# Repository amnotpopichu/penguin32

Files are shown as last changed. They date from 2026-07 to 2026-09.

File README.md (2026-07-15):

# penguin32
Penguin32 is a esp32 devboard developed on the esp32 s3fn8 board but with a big penguin on it. why penguin? why not? the main goal here was to develop and learn bare chip work

# Firmware + CAD
N/A, all the necessary programs are preflashed onto the s3 chip. Also no cad for obvious reasons, its just a devboard

# Images
Not sure why some of the models dont actaully render, and some are upside down, so forgive the pcb looking kinda odd.
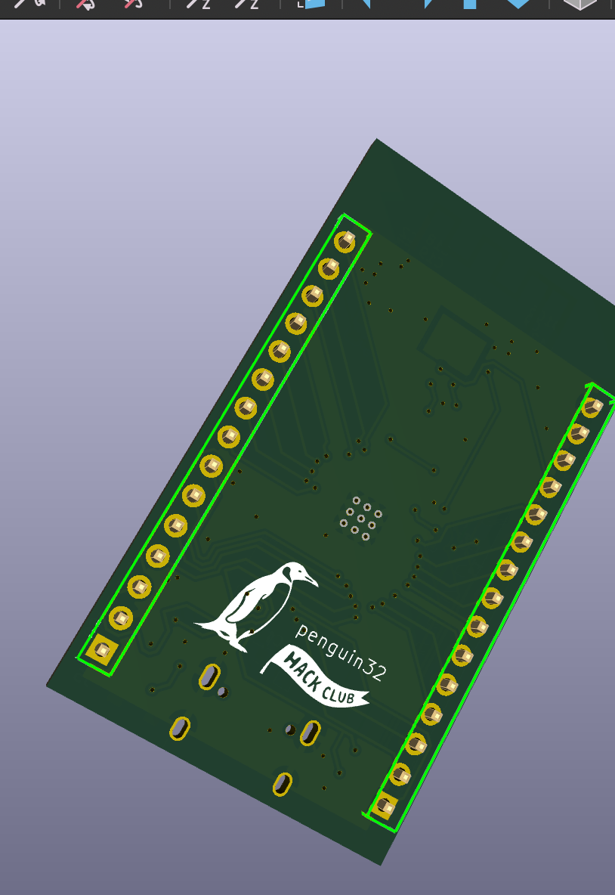
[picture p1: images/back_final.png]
image name

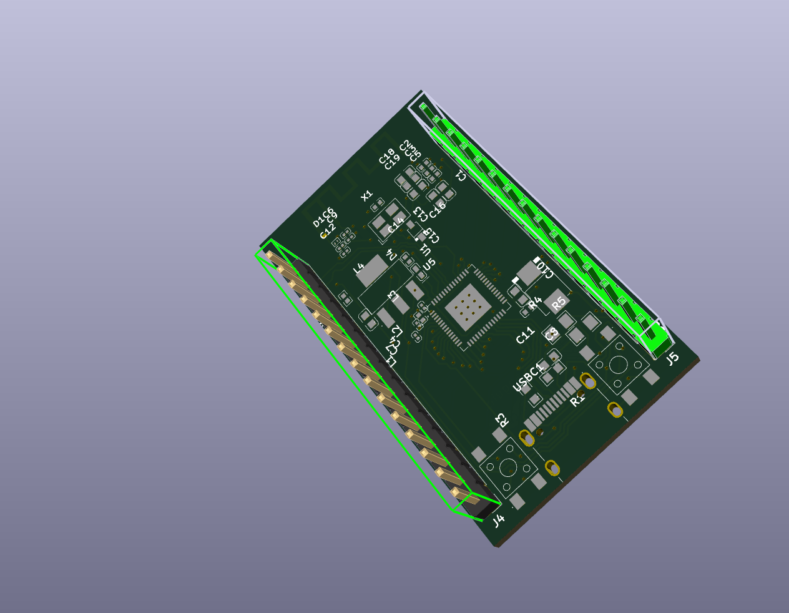
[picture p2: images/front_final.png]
image name

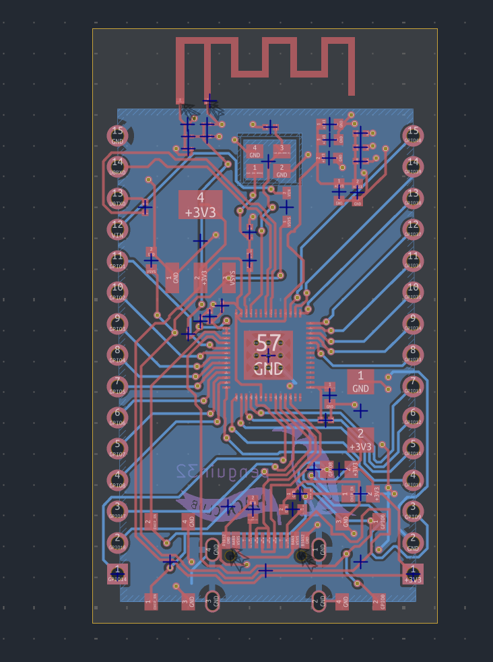
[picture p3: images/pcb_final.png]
image name

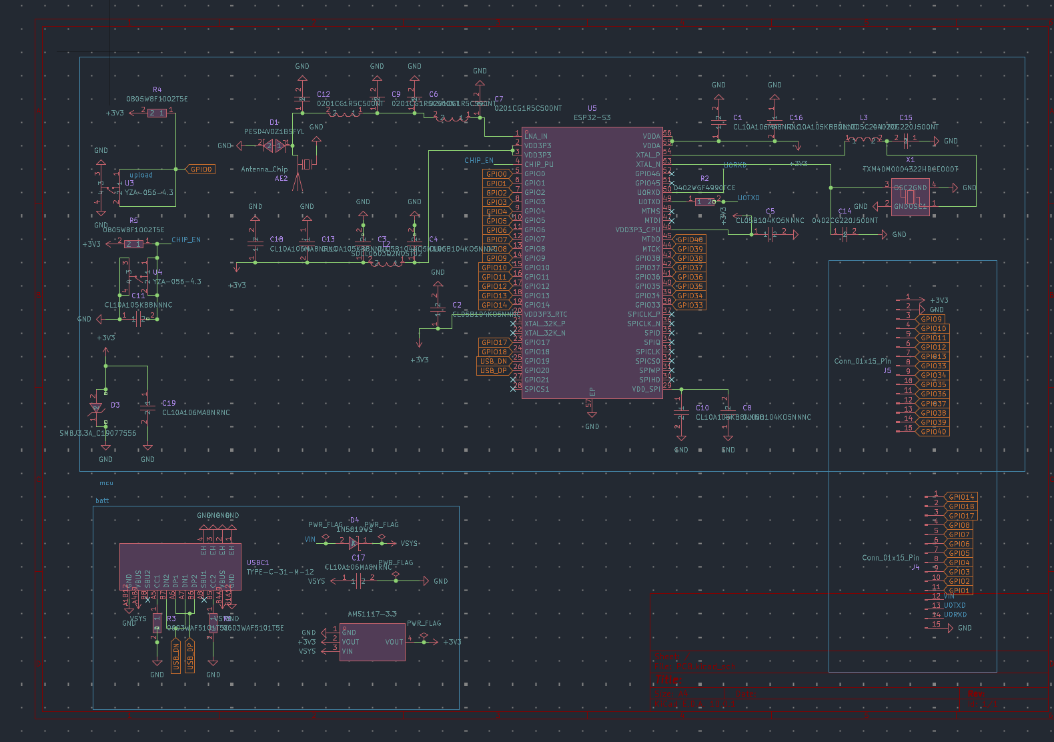
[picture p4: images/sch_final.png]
image name

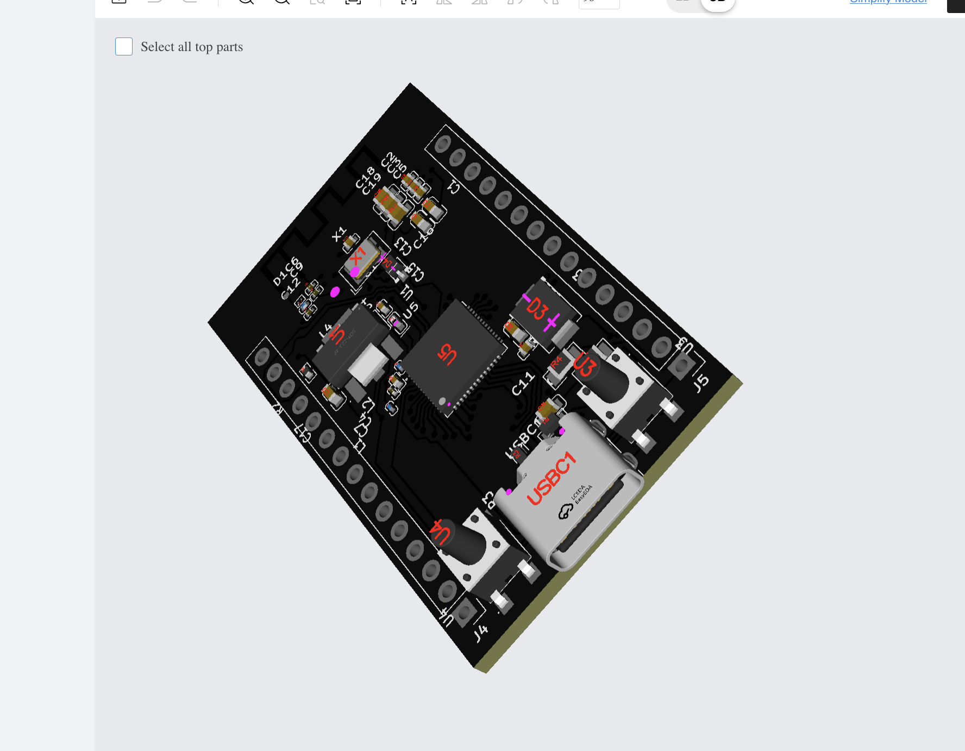
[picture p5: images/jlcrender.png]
image name


# Notes
flash not needed thanks to the onboard flash. this is my first time doing bare chip development so im pretty happy with how it turned out given i did it in about 3 days to attempt to qualify for outpost. Honestly i can't believe some of the stuff (routing) took me so long, but i guess i finished at the end of the day so its fine. Also i have two seperate BOMs, a regular BOM, and then a BOM for specific pick and place components. Also i had to use 5 pcba instead of 2, because otherwise it would have made do standard pcba -- which is more expenisve. gsdl doesnt work because jlc doesn't allow it over a certain price.

| Line Item | Amount (USD) |
|---|---|
| MERCHANDISE TOTAL | 65.78 |
| SHIPPING CHARGE | 42.78 |
| Customs duties & taxes | 17.78 |
| DISCOUNT | -15.00 |
| SALES TAX | 4.90 |
| ORDER TOTAL | 116.24 |

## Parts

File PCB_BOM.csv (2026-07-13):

Reference | Qty | Value | DNP | Exclude from BOM | Exclude from Board | Footprint | Datasheet
AE2 | 1 | Antenna_Chip |  |  |  | esp32 antenna:ESPRESSIF_ESP32_MIFA_2.4GHz_Right
C1,C17,C18,C19 | 4 | CL10A106MA8NRNC |  |  |  | easyeda2kicad:C0603 | https://lcsc.com/product-detail/Multilayer-Ceramic-Capacitors-MLCC-SMD-SMT_SAMSUNG_CL10A106MA8NRNC_10uF-106-20-25V_C96446.html
C2,C3,C4,C5,C8 | 5 | CL05B104KO5NNNC |  |  |  | easyeda2kicad:C0402 | https://lcsc.com/product-detail/Multilayer-Ceramic-Capacitors-MLCC-SMD-SMT_SAMSUNG_CL05B104KO5NNNC_100nF-104-10-16V_C1525.html
C6,C7,C9,C12 | 4 | 0201CG1R5C500NT |  |  |  | easyeda2kicad:C0201 | https://lcsc.com/product-detail/Multilayer-Ceramic-Capacitors-MLCC-SMD-SMT_1-5pF-1R5-0-25pF-50V_C50389.html
C10,C11,C13,C16 | 4 | CL10A105KB8NNNC |  |  |  | easyeda2kicad:C0603 | https://lcsc.com/product-detail/Multilayer-Ceramic-Capacitors-MLCC-SMD-SMT_SAMSUNG_CL10A105KB8NNNC_1uF-105-10-50V_C15849.html
C14,C15 | 2 | 0402CG220J500NT |  |  |  | easyeda2kicad:C0402 | https://lcsc.com/product-detail/Multilayer-Ceramic-Capacitors-MLCC-SMD-SMT_22pF-220-5-50V_C1555.html
D1 | 1 | PESD4V0Z1BSFYL |  |  |  | easyeda2kicad:DSN0603-2_L0.7-W0.3-P0.40-BI | https://lcsc.com/product-detail/presales_Nexperia-PESD4V0Z1BSFYL_C552547.html
D3 | 1 | SMBJ3.3A_C19077556 |  |  |  | easyeda2kicad:SMB_L4.6-W3.6-LS5.3-RD | https://www.lcsc.com/datasheet/C19077556.pdf
D4 | 1 | 1N5819WS |  |  |  | easyeda2kicad:SOD-323_L1.8-W1.3-LS2.5-RD | https://lcsc.com/product-detail/Others_B5819WS_C191023.html
J4,J5 | 2 | Conn_01x15_Pin |  |  |  | Connector_PinHeader_2.54mm:PinHeader_1x15_P2.54mm_Vertical
L1,L2,L4 | 3 | SDCL0603Q2N0ST02 |  |  |  | easyeda2kicad:L0201 | https://lcsc.com/product-detail/HF-Inductors_2nH-0-3nH_C42142.html
L3 | 1 | SDCL1005C24NJTDF |  |  |  | easyeda2kicad:L0402-RD | https://lcsc.com/product-detail/Inductors-SMD_24nH-5_C74301.html
R1,R3 | 2 | 0603WAF5101T5E |  |  |  | easyeda2kicad:R0603 | https://lcsc.com/product-detail/Chip-Resistor-Surface-Mount-UniOhm_5-1KR-5101-1_C23186.html
R2 | 1 | 0402WGF4990TCE |  |  |  | easyeda2kicad:R0402 | https://lcsc.com/product-detail/Chip-Resistor-Surface-Mount-UniOhm_499R-4990-1_C4125.html
R4,R5 | 2 | 0805W8F1002T5E |  |  |  | easyeda2kicad:R0805 | https://lcsc.com/product-detail/Chip-Resistor-Surface-Mount-UniOhm_10KR-1002-1_C17414.html
U1 | 1 | AMS1117-3.3 |  |  |  | easyeda2kicad:SOT-223-3_L6.5-W3.4-P2.30-LS7.0-BR | https://lcsc.com/product-detail/Low-Dropout-Regulators-LDO_AMS_AMS1117-3-3_AMS1117-3-3_C6186.html
U3,U4 | 2 | YZA-056-4.3 |  |  |  | easyeda2kicad:SW-SMD_4P-L4.5-W4.5-P3.00-LS6.8 | https://www.lcsc.com/datasheet/C49108646.pdf
U5 | 1 | ESP32-S3 |  |  |  | easyeda2kicad:QFN-56_L7.0-W7.0-P0.40-TL-EP4.0 | https://www.lcsc.com/datasheet/C2913196.pdf
USBC1 | 1 | TYPE-C-31-M-12 |  |  |  | easyeda2kicad:USB-C_SMD-TYPE-C-31-M-12_1 | https://lcsc.com/product-detail/USB-Type-C_Korean-Hroparts-Elec-TYPE-C-31-M-12_C165948.html
X1 | 1 | TXM40M0004322HBCEO00T |  |  |  | easyeda2kicad:CRYSTAL-SMD_4P-L3.2-W2.5-BL-2 | https://lcsc.com/product-detail/_Zhejiang-Abel-Elec-TXM40M0004322HBCEO00T_C284179.html

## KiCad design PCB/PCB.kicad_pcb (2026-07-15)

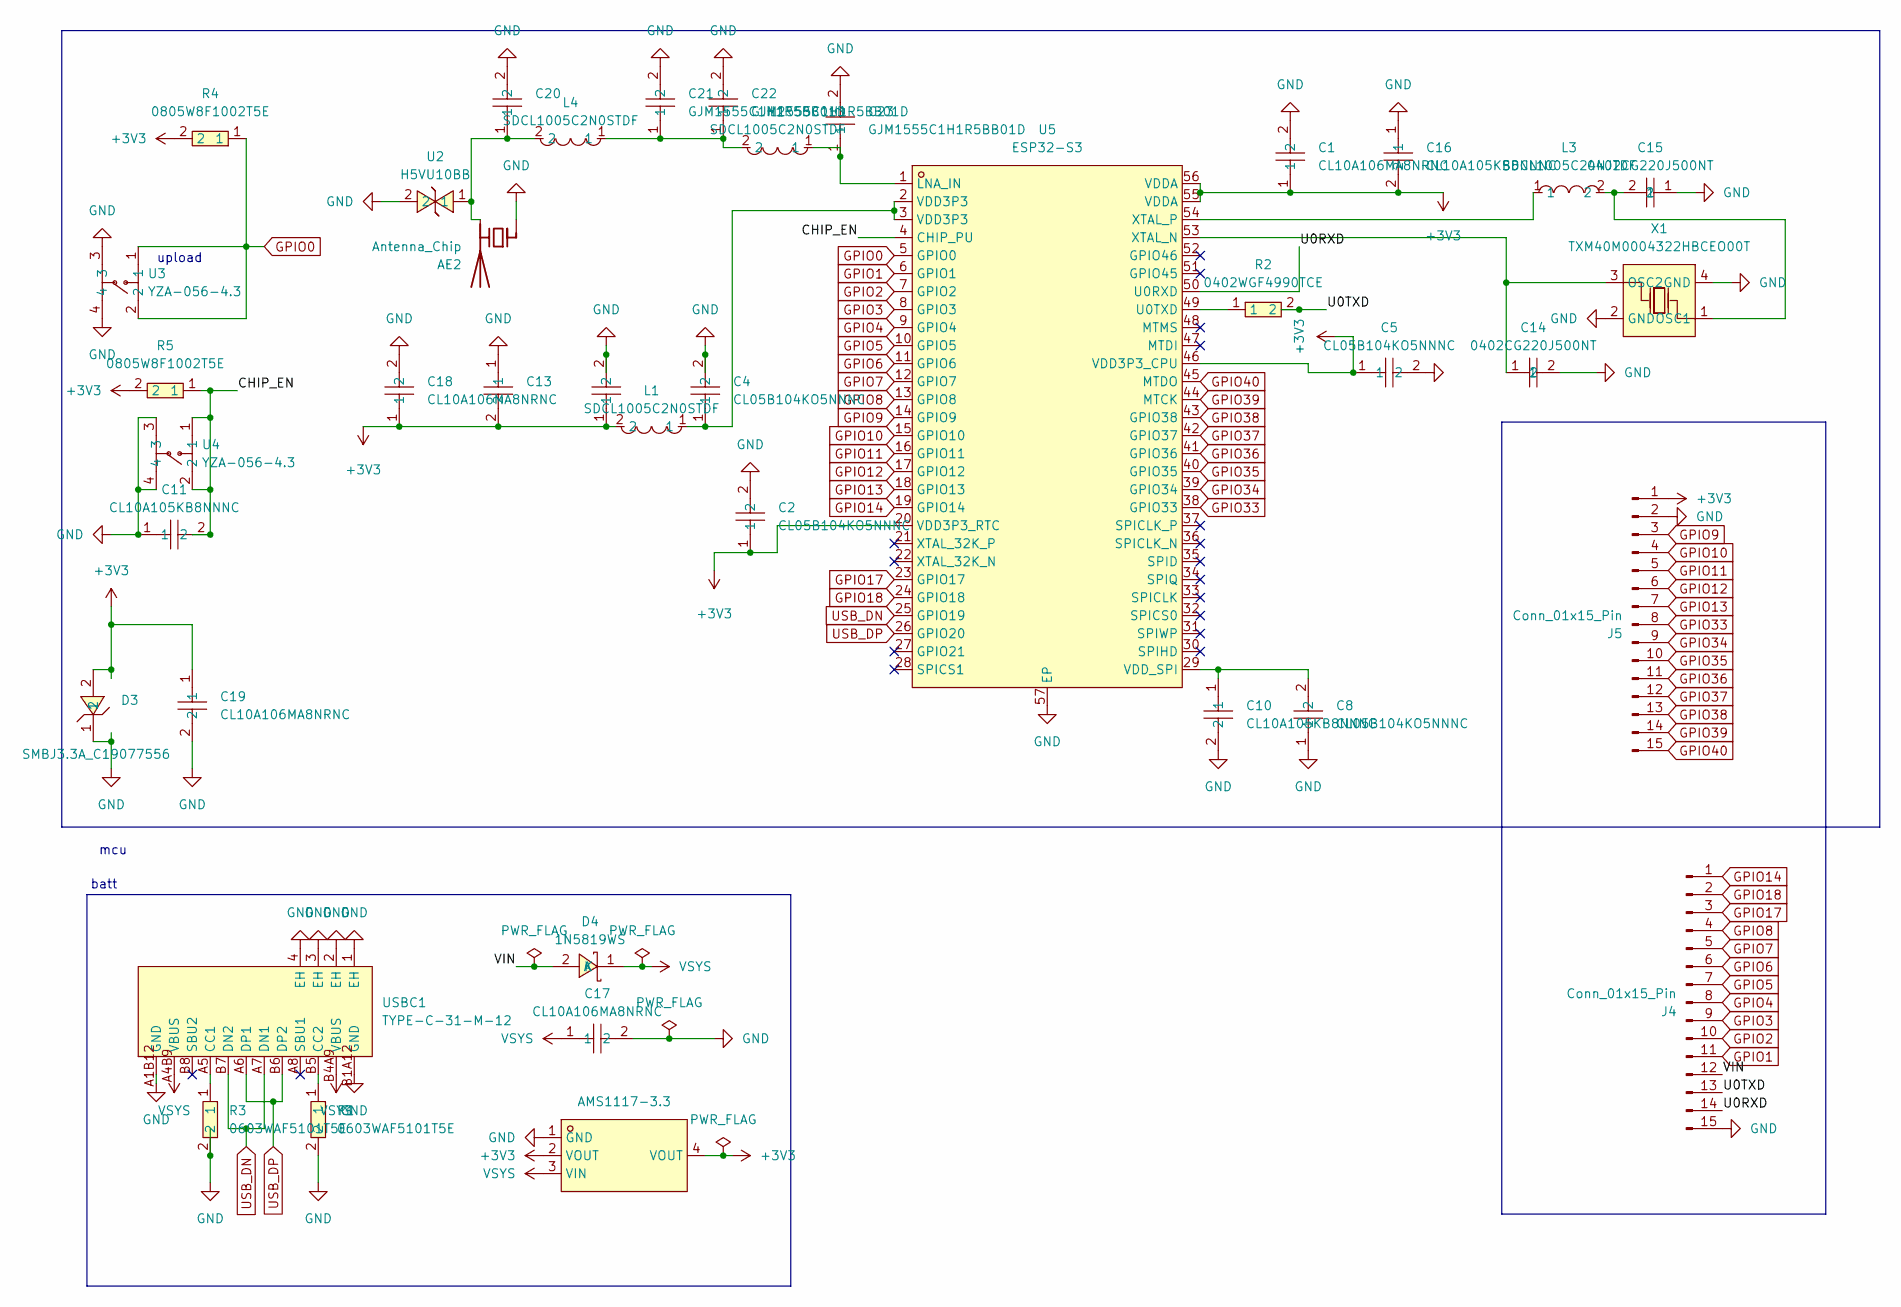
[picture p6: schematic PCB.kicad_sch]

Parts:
AE2: Antenna_Chip; ESPRESSIF_ESP32_MIFA_2.4GHz_Right
C1, C17, C18, C19: CL10A106MA8NRNC; C0603; MPN CL10A106MA8NRNC; LCSC Part C96446
C2, C3, C4, C5, C8: CL05B104KO5NNNC; C0402; MPN CL05B104KO5NNNC; LCSC Part C1525
C10, C11, C13, C16: CL10A105KB8NNNC; C0603; MPN CL10A105KB8NNNC; LCSC Part C15849
C14, C15: 0402CG220J500NT; C0402; MPN 0402CG220J500NT; LCSC Part C1555
C20, C21, C22, C23: GJM1555C1H1R5BB01D; C0402; MPN GJM1555C1H1R5BB01D; LCSC Part C76900
D3: SMBJ3.3A_C19077556; SMB_L4.6-W3.6-LS5.3-RD; MPN SMBJ3.3A; LCSC Part C19077556
D4: 1N5819WS; SOD-323_L1.8-W1.3-LS2.5-RD; MPN 1N5819WS; LCSC Part C191023
J4, J5: Conn_01x15_Pin; PinHeader_1x15_P2.54mm_Vertical
L1, L2, L4: SDCL1005C2N0STDF; L0402; MPN SDCL1005C2N0STDF; LCSC Part C43365
L3: SDCL1005C24NJTDF; L0402-RD; MPN SDCL1005C24NJTDF; LCSC Part C74301
R1, R3: 0603WAF5101T5E; R0603; MPN 0603WAF5101T5E; LCSC Part C23186
R2: 0402WGF4990TCE; R0402; MPN 0402WGF4990TCE; LCSC Part C4125
R4, R5: 0805W8F1002T5E; R0805; MPN 0805W8F1002T5E; LCSC Part C17414
U1: AMS1117-3.3; SOT-223-3_L6.5-W3.4-P2.30-LS7.0-BR; MPN AMS1117-3.3; LCSC Part C6186
U2: H5VU10BB; DFN1006-2L-BI; MPN H5VU10BB; LCSC Part C20615786
U3, U4: YZA-056-4.3; SW-SMD_4P-L4.5-W4.5-P3.00-LS6.8; MPN YZA-056-4.3; LCSC Part C49108646
U5: ESP32-S3; QFN-56_L7.0-W7.0-P0.40-TL-EP4.0; MPN ESP32-S3FN8; LCSC Part C2913196
USBC1: TYPE-C-31-M-12; USB-C_SMD-TYPE-C-31-M-12_1; MPN TYPE-C-31-M-12; LCSC Part C165948
X1: TXM40M0004322HBCEO00T; CRYSTAL-SMD_4P-L3.2-W2.5-BL-2; MPN TXM40M0004322HBCEO00T; LCSC Part C284179

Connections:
+3V3: C1.1, C2.1, C3.1, C5.1, C13.2, C16.2, C18.1, C19.1, D3.2, J5.1, L1.2, R4.2, R5.2, U1.2 (VOUT), U1.4 (VOUT), U5.20 (VDD3P3_RTC), U5.46 (VDD3P3_CPU), U5.55 (VDDA), U5.56 (VDDA)
/CHIP_EN: C11.2, R5.1, U4.1, U4.2, U5.4 (CHIP_PU)
/U0RXD: J4.14, U5.50 (U0RXD)
/U0TXD: J4.13, R2.2
/VIN: D4.2 (A), J4.12
GND: AE2.1 (FEED), C1.2, C2.2, C3.2, C4.2, C5.2, C8.1, C10.2, C11.1, C13.1, C14.2, C15.1, C16.1, C17.2, C18.2, C19.2, C20.2, C21.2, C22.2, C23.2, D3.1, J4.15, J5.2, R1.2, R3.2, U1.1 (GND), U2.2, U3.3, U3.4, U4.3, U4.4, U5.57 (EP), USBC1.1 (EH), USBC1.2 (EH), USBC1.3 (EH), USBC1.4 (EH), USBC1.A1B12 (GND), USBC1.B1A12 (GND), X1.2 (GND), X1.4 (GND)
GPIO0: R4.1, U3.1, U3.2, U5.5 (GPIO0)
GPIO1: J4.11, U5.6 (GPIO1)
GPIO2: J4.10, U5.7 (GPIO2)
GPIO3: J4.9, U5.8 (GPIO3)
GPIO4: J4.8, U5.9 (GPIO4)
GPIO5: J4.7, U5.10 (GPIO5)
GPIO6: J4.6, U5.11 (GPIO6)
GPIO7: J4.5, U5.12 (GPIO7)
GPIO8: J4.4, U5.13 (GPIO8)
GPIO9: J5.3, U5.14 (GPIO9)
GPIO10: J5.4, U5.15 (GPIO10)
GPIO11: J5.5, U5.16 (GPIO11)
GPIO12: J5.6, U5.17 (GPIO12)
GPIO13: J5.7, U5.18 (GPIO13)
GPIO14: J4.1, U5.19 (GPIO14)
GPIO17: J4.3, U5.23 (GPIO17)
GPIO18: J4.2, U5.24 (GPIO18)
GPIO33: J5.8, U5.38 (GPIO33)
GPIO34: J5.9, U5.39 (GPIO34)
GPIO35: J5.10, U5.40 (GPIO35)
GPIO36: J5.11, U5.41 (GPIO36)
GPIO37: J5.12, U5.42 (GPIO37)
GPIO38: J5.13, U5.43 (GPIO38)
GPIO39: J5.14, U5.44 (MTCK)
GPIO40: J5.15, U5.45 (MTDO)
unnamed: AE2.2 (PCB_Trace), C20.1, L4.2, U2.1
unnamed: C4.1, L1.1, U5.2 (VDD3P3), U5.3 (VDD3P3)
unnamed: C21.1, C22.1, L2.2, L4.1
unnamed: C23.1, L2.1, U5.1 (LNA_IN)
unnamed: R2.1, U5.49 (U0TXD)
unnamed: C8.2, C10.1, U5.29 (VDD_SPI)
unnamed: C14.1, U5.53 (XTAL_N), X1.3 (OSC2)
unnamed: L3.1, U5.54 (XTAL_P)
unnamed: R3.1, USBC1.A5 (CC1)
unnamed: R1.1, USBC1.B5 (CC2)
unnamed: C15.2, L3.2, X1.1 (OSC1)
USB_DN: U5.25 (GPIO19), USBC1.A7 (DN1), USBC1.B7 (DN2)
USB_DP: U5.26 (GPIO20), USBC1.A6 (DP1), USBC1.B6 (DP2)
VSYS: C17.1, D4.1 (K), U1.3 (VIN), USBC1.A4B9 (VBUS), USBC1.B4A9 (VBUS)

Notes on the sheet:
batt
upload
mcu

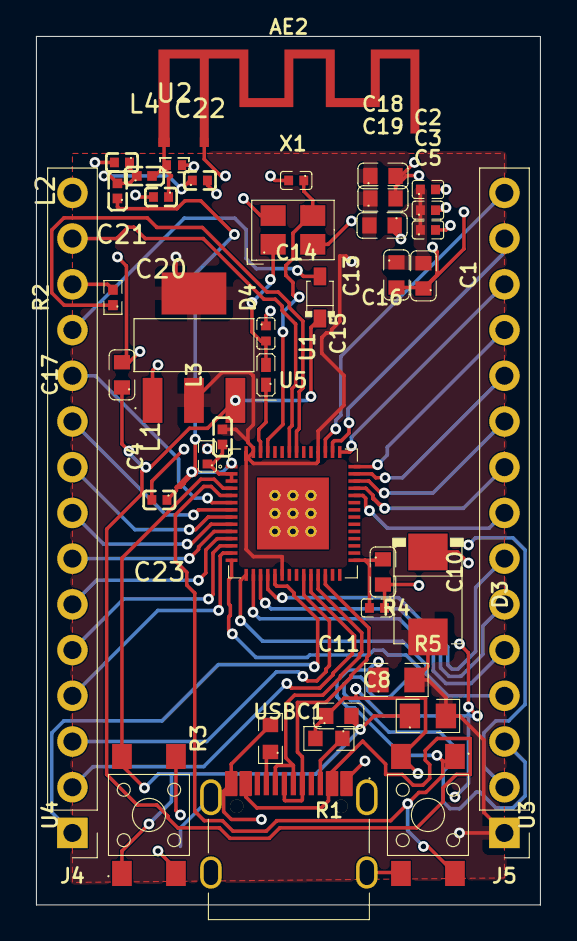
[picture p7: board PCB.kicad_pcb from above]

Board: 2 copper layers, 28.0 x 48.2 mm, 40 parts (0 on the bottom side), 45 nets.

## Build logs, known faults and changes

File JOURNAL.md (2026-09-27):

---
title: "Penguin32"
author: "Leo Hsia"
description: "Penguin32 is a esp32 devboard but with a big penguin on it. why penguin? why not?"
---
# September 8th
long story short they arrived -- i didnt journal, but there were issues with it heating up without powering on. eventually i grabbed a mulitimeter and tested it, finding the LDO only returned 0.5v. After asking around Ace6rings helped out a lot, and noticed I had forgotten some decop capacitators next to the LDO. very sad that i wasted so much, but the lesson is to never forget to read ldo datasheets (i ignorantly assumed ldos didnt need decoup caps). this project is kinda chopped now but next devboard WILL not have these mistakes

# Jul 14th: I DID IT
after emaliing jlcpcb i finally got a 15 dollar coupon to stay under my limit!! LETS GOOOO. order is now placed
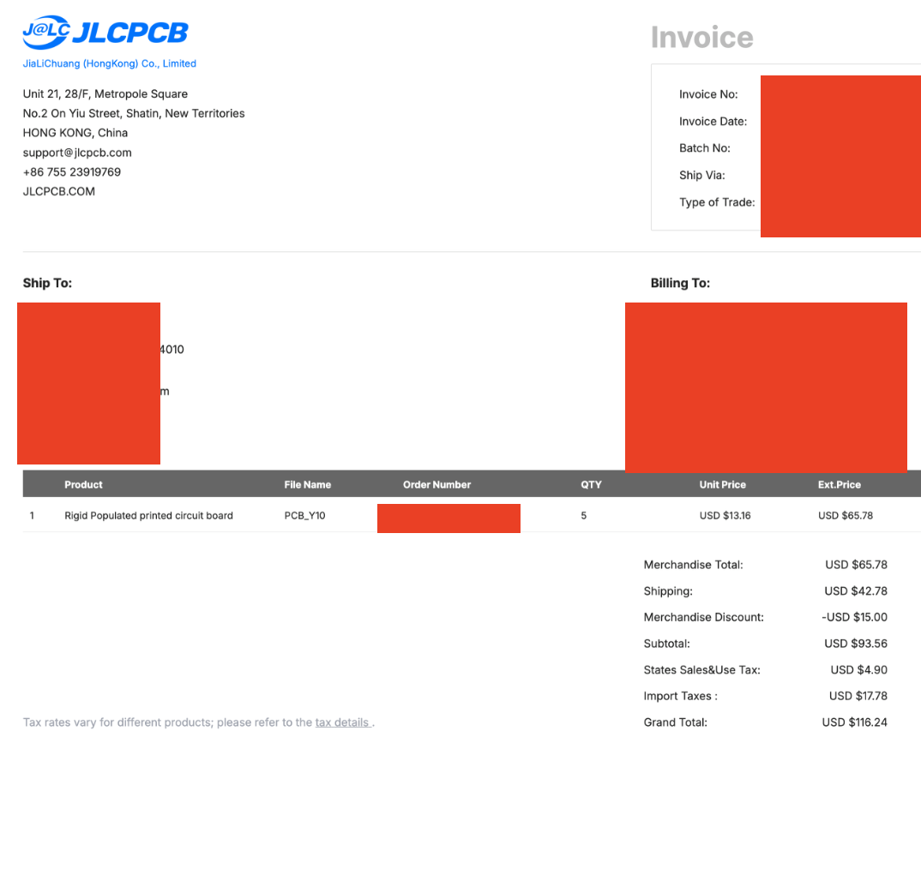
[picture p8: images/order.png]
image name

**Total time spent: 0.5 hours**

# Jul 13th: PCBA BOM
soo erm jlc decided they were going to slap on 60 dollars in hidden fees if i dont redo some parts (because im stupid and did small foot prints and that needs standard pcba instead of economic). went back and sourced a diff diode because of stock. also tried their customer support to get the review, reviewed on a second platform after being blocked on trust pilot (im trying again). tldr i just need 12 extra dollars. (or a 12 dollar discount) because gdsl is mean

**Total time spent: 0.5 hours**

# Jul 12th: rewire
I rerouted everything three times. i wish i was joking. anywyas some of the more techical and fun stuff. 1. rerouted because i changed some stuff where i was deciding how my headers should work (to optimize for placement) 2. changed because i optimized BOM. i had something that needed 2k capacitaors minmium order so i changed it to something else, and then in the process rerouted. 3. i just wasnt getting it done. i think with my past few attempts it just wasnt working, so i rerouted everything. All in all, i think there are a few things i learned 1. i should use a second plane next time, ie a 3v3 pwr plane instead of manually routing everything 2. sometimes i need to mess with footprints. i had to change some of the thermal pins to actaully route to ground for it to work, and then also had to learn about net ties (to stop kicad from yelling at me). didnt solve it, so i also learned about 4. ignoring drc when you are 100% sure you are right, and adding a comment. Also added some silkscreen stuff With a penguin and a cool hatck club flag.

image name
image name
image name
**Total time spent: 2.5 hours**
# Jul 11th: pcb wiring
i wish i was joking im writing this journal while im not even done with my wiring (half way through this session). the diff pair wiring has taken me AN HOUR. im so serious. i cannot for some reason get the width to match up and it took me >1 hour to actaully get it to work. genuienly i keep trying to fix this width and then having to fix the length and then over and over and over again. after wayy to long i have fully gotten what i believe to be as best possible solution, with the length delta to be <0.5mmish. time to move onto actaully doing ground pours! in total i logged 140 minutes but im going to self deflate to 105 because there were times i wasn't as productive enough + spending a full hour on diff pairs is ridiculous (even tho it took me that long). anyways the second hour was spent working on routing the thing and moving stuff around becasue i HATE this so much i should have managed this 10x better before starting tbh. im considering restarting routing at some point if this doesn't work out because honestly it doesn't look too good right now and im worried it wont work.can
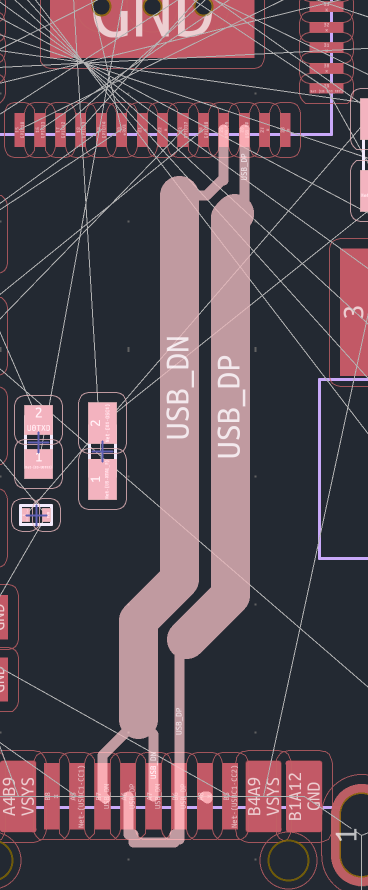
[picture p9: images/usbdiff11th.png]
image name

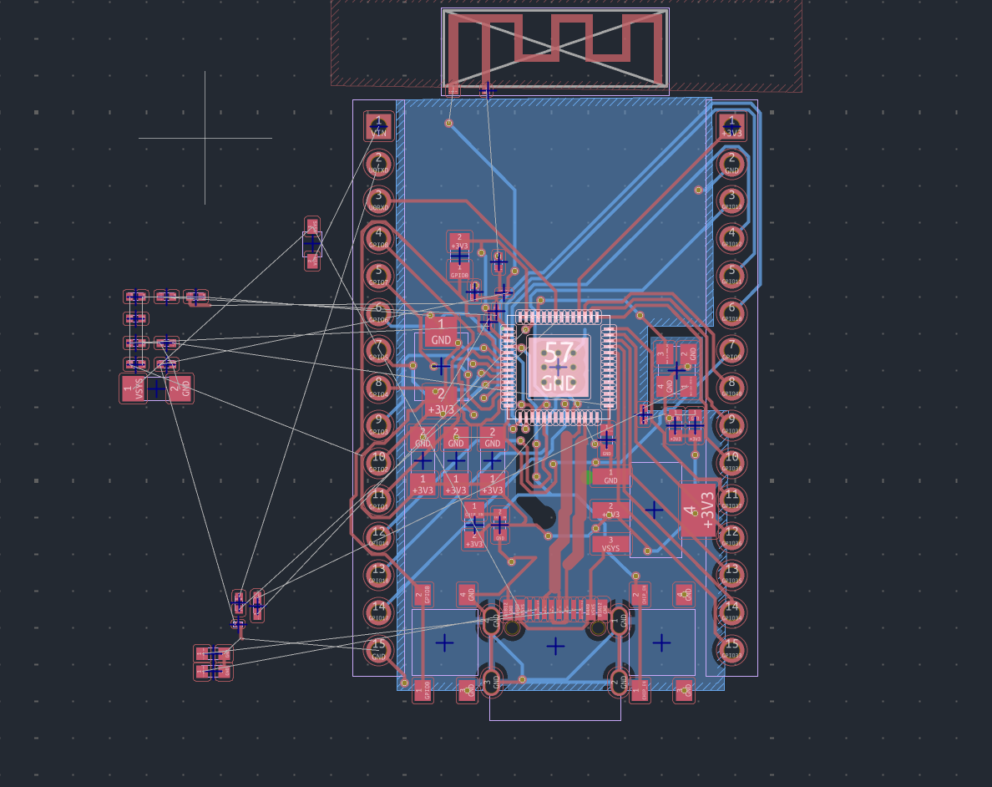
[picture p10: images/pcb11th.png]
image name

**Total time spent: 1.75 hours**

# Jul 11th: schematic done
assigned a lot of footprints cross checking parts with LCSC. took me stupidly long espeically because i have been struggling a lot with deal of the capicators because there is osmehow ZERO data about capacitators for certian parts of the wiring of the antenna. Luckily i managed to find a reasonabile range and have finished ALL the footprints which took a really long time. 
I also ended up catching myself with one of my diodes, and then added a final decopuler. (erc is lying to me and half of them is like pwr flag issues which arent even real). big thanks to [@jblitzar](https://github.com/jblitzar) for advice info on capacitator information for antenna.
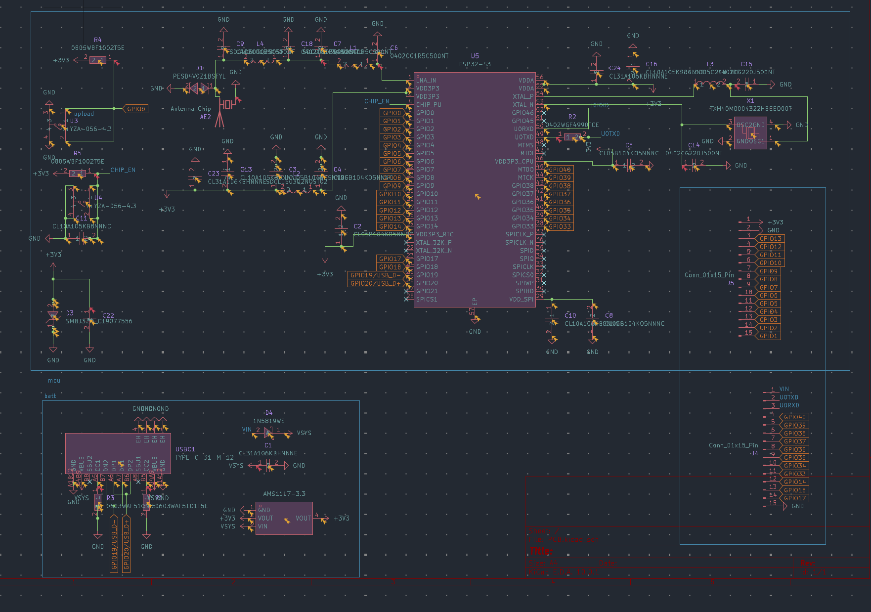
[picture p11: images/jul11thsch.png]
image name

**Total time spent: 1.5 hours**
# Jul 11th: short jouranl but came back rq
ok so guess who changed the ENTIRE esp32 schematic cus i needed to change the footprint for BOM later (im trying to limit as much of that pick and place instruction stuff). its pretty simpel i just rewired and moved things so image sort of speaks for itself. was not fun 0/10 would not recommend.
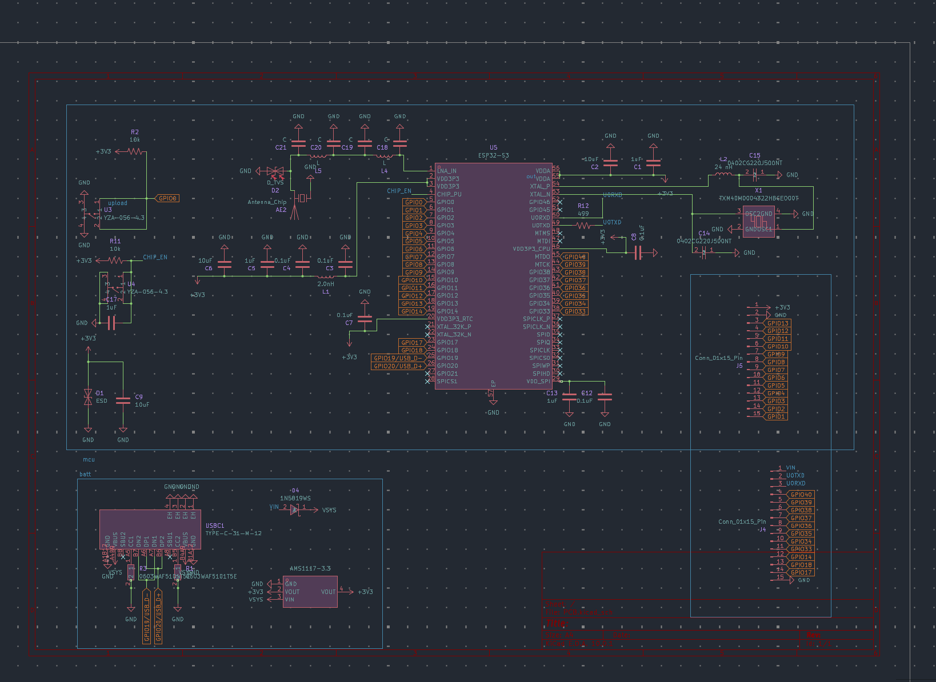
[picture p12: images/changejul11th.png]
image name

**Total time spent: 0.25 hours**
# Jul 10+11th: worked so much turned a new day 
footprint lowk got hands. okay but in all seriousness a few things happened.
1. crashed out at kicad because it was glitching out
2. crashed out at easyeda because it wasnt so easy (i thought i had to use easyeda to use easyeda2kicad until i read the docs)
3. crashed out at kicad again (this time for finding the symobls library instead of the package manager)
4. am actively crying over sourcing parts this is so sad
okay but really from some good advice from [@hekinav](https://github.com/hekinav) i simplified a lot of my battery stuff and used an LDO instead of a buck converter (because i dont have anything to boost!!!)i also started assigning a lot of footprints which is super fun (i hate it so much) but its so satisifying to keep on going through and checking things off. self (over)deflating myself a little because i got a bit distracted yapping so going from 2 hours to listed below
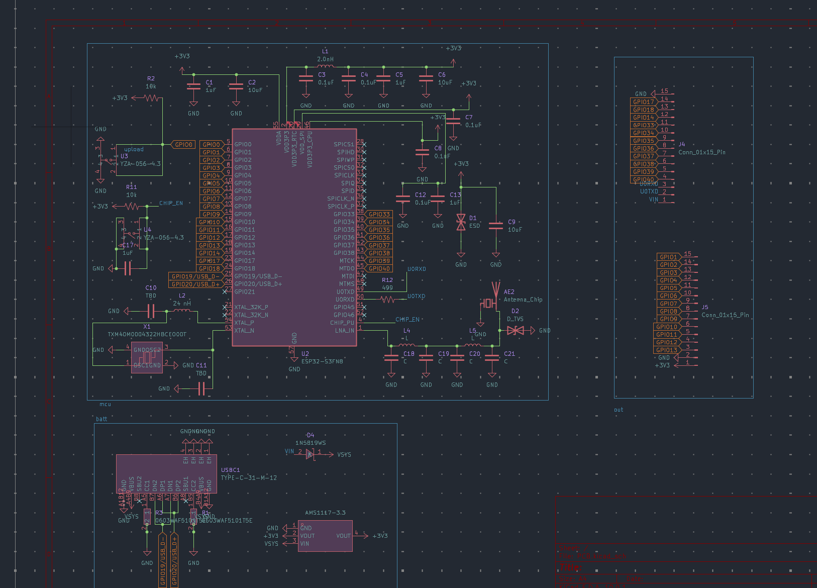
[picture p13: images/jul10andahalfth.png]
image name

**Total time spent: 1.25 hours**
# Jul 10th: sch work
yippie today has been focused on wiring stuff and getting it ready for devboard.
work includes: pin headers yay they exist now, a vin port! yippie hopefully this diode works, and i yoinked my esp32 from upstairs to figure out what to do. i also learned how antennas kinda work, and turns out its not really a thing you stick on as much as it is just traces which is kinda cool! so i imported from github. anywyas rest of time is just reviewing schematic + ect.
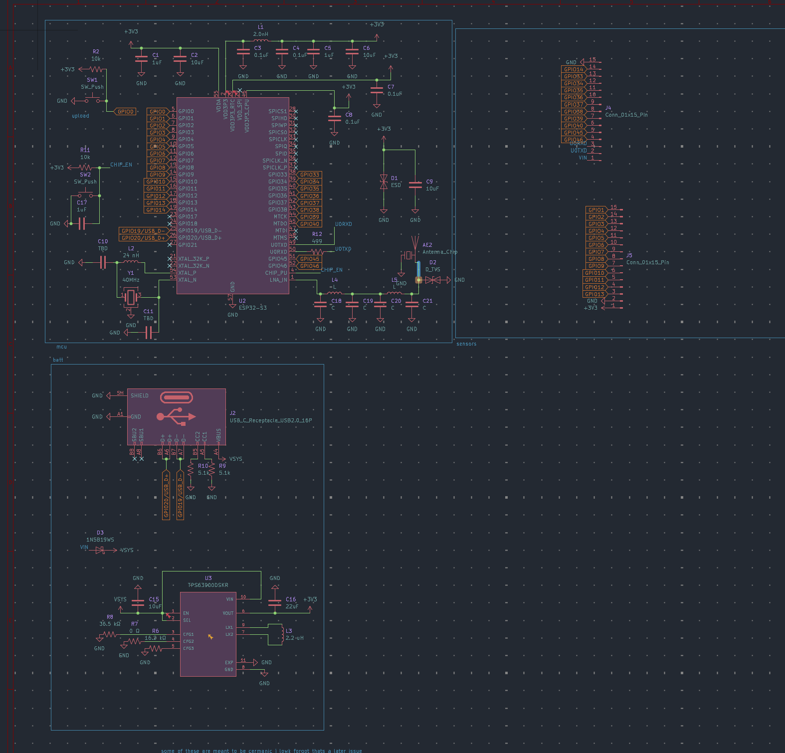
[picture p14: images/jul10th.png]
image name

**Total time spent: 0.75 hours**
# July 9th: Starting
Today i mainly just imported a bunch of stuff from a previous esp project, that was incomplete. This is super helpful, because i dont have to spend as much time doing the bare chip schematic work, but will have to do a lot of pcb work, and finish it up because I never included wifi + some other things. Most work included the LNA_in + rewiring some power lines
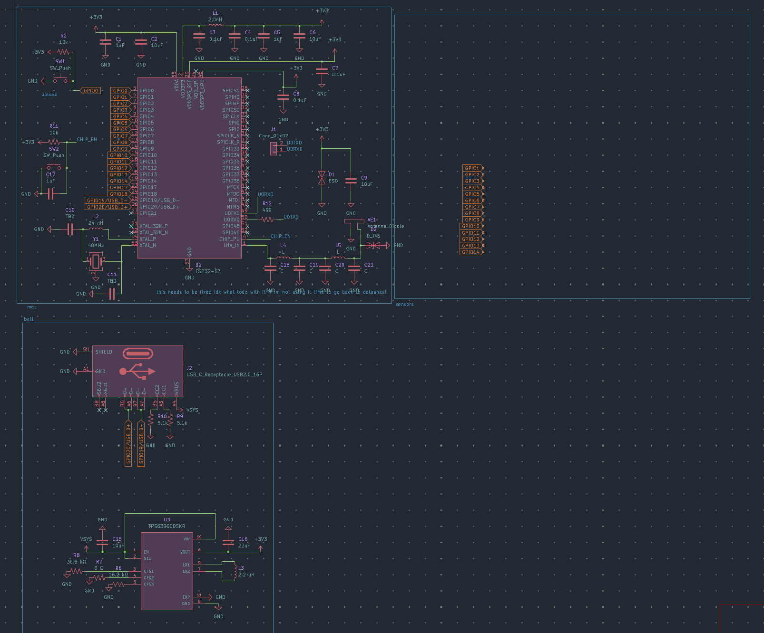
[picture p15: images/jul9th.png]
image name

**Total time spent: 0.5 hours**

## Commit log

2026-07-12 pcb work before big revision
    [PCB.csv, PCB.kicad_pcb, PCB.kicad_sch]
2026-07-12 restart again
    [PCB.kicad_pcb]
2026-07-13 final commit i hope
    [JLC_BOM.csv, PCB.kicad_pcb, PCB.kicad_sch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]
2026-07-13 idk why some files said they were changed
    [JLC_BOM.csv]
2026-07-15 final commit
    [JLC_BOM.csv, PCB.kicad_pcb, PCB.kicad_sch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]
